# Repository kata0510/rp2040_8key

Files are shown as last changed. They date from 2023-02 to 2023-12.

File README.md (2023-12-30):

# rp2040_8key
[RP2040で作る自作キーボード](https://booth.pm/ja/items/4444554)の第4章で設計したキーボード基板です。

RP2040を用いた8キーの自作キーボード基板です。

検証用のためケースなどは付属しません。RP2040を用いた実際の動作と部品実装例の参考としてご利用ください。

## ファームウェア
ファームウェアは以下のリポジトリの`rp2040_8key`ブランチにあります。Cloneし、ブランチを切り替えてからqmk flashを実行してください。

[https://github.com/kata0510/qmk_firmware/tree/rp2040_8key](https://github.com/kata0510/qmk_firmware/tree/rp2040_8key)

QMK Firmwareのビルド環境未作成の場合は、公式ドキュメントもしくは[RP2040で作る自作キーボード](https://booth.pm/ja/items/4444554)の第2章を参考に構築してください。

[https://docs.qmk.fm/#/newbs_getting_started](https://docs.qmk.fm/#/newbs_getting_started)

```
$ git switch rp2040_8key
$ qmk flash -kb rp2040_8key -km default
```

firmwareフォルダ内にあるファームウェアは書籍の参考用として用意しているものです。お手持ちのqmk_firmwareリポジトリの`keyboards/`以下にフォルダをコピーしても書き込み可能です。

## 基板データについて
基板データは`PCB/`フォルダ以下にあります。Kicad7閲覧することができます。

JLCPCBのPCB Assemblyサービスを想定した部品ファイル(BOM)と配置ファイル(CPL)は`gerver/`フォルダ内にあります。

部品の在庫状況は日々返送するため、在庫無しの場合は同じ性能の部品を選択して製造してください。

## 不具合/問い合わせ
基板の不具合、お問い合わせに関しては以下のメールアドレス、もしくはDiscord(yuchi51)までご連絡ください。
```
yuchi.kbd@gmail.com
```

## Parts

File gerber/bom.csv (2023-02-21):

Comment | Val | Designator | Footprint | JLCPCB Part #
 | 10u | C1-2 | C_0402_1005Metric | C1644
 | 100n | C3-11,C14 | C_0402_1005Metric | C1525
 | 2.2uF | C12-13,C15 | C_0402_1005Metric | C307418
 | D_Small | D1-8 | SOD-123 | C109203
 | 6V 0.5A | F1 | Fuse_0603_1608Metric | C122965
 | USB_C_Receptacle | J1 | USB_C_Receptacle_HRO_TYPE-C-31-M-12 | C165948
 | 1k | R1,R6,R8 | R_0402_1005Metric | C11702
 | 5.1k | R2-3 | R_0402_1005Metric | C25905
 | 27 | R4-5, | R_0402_1005Metric | C25100
 | 10k | R7 | R_0402_1005Metric | C25744
 | 3A/10V/280mV | SD1 | D_SOD-123 | C8598
 | LED_GREEN | STLED1 | LED_0402_1005Metric | C130723
 | SWBoot | SW9-10 | SW_Push_1P1T_NO_Vertical_Wuerth_434133025816 | C92589
 | NCP1117-3.3_SOT223 | U1 | SOT-223 | C146799
 | RP2040 | U2 | QFN-56-1EP_7x7mm_P0.4mm_EP3.2x3.2mm | C2040
 | W25Q128JVPIQ | U3 | WSON-8-1EP_6x5mm_P1.27mm_EP3.4x4.3mm | C97521
 | 12MHz_Q22FA23V00285 | Y1 | Resonator_SMD_Murata_CSTxExxV-3Pin_3.0x1.1mm | C341520

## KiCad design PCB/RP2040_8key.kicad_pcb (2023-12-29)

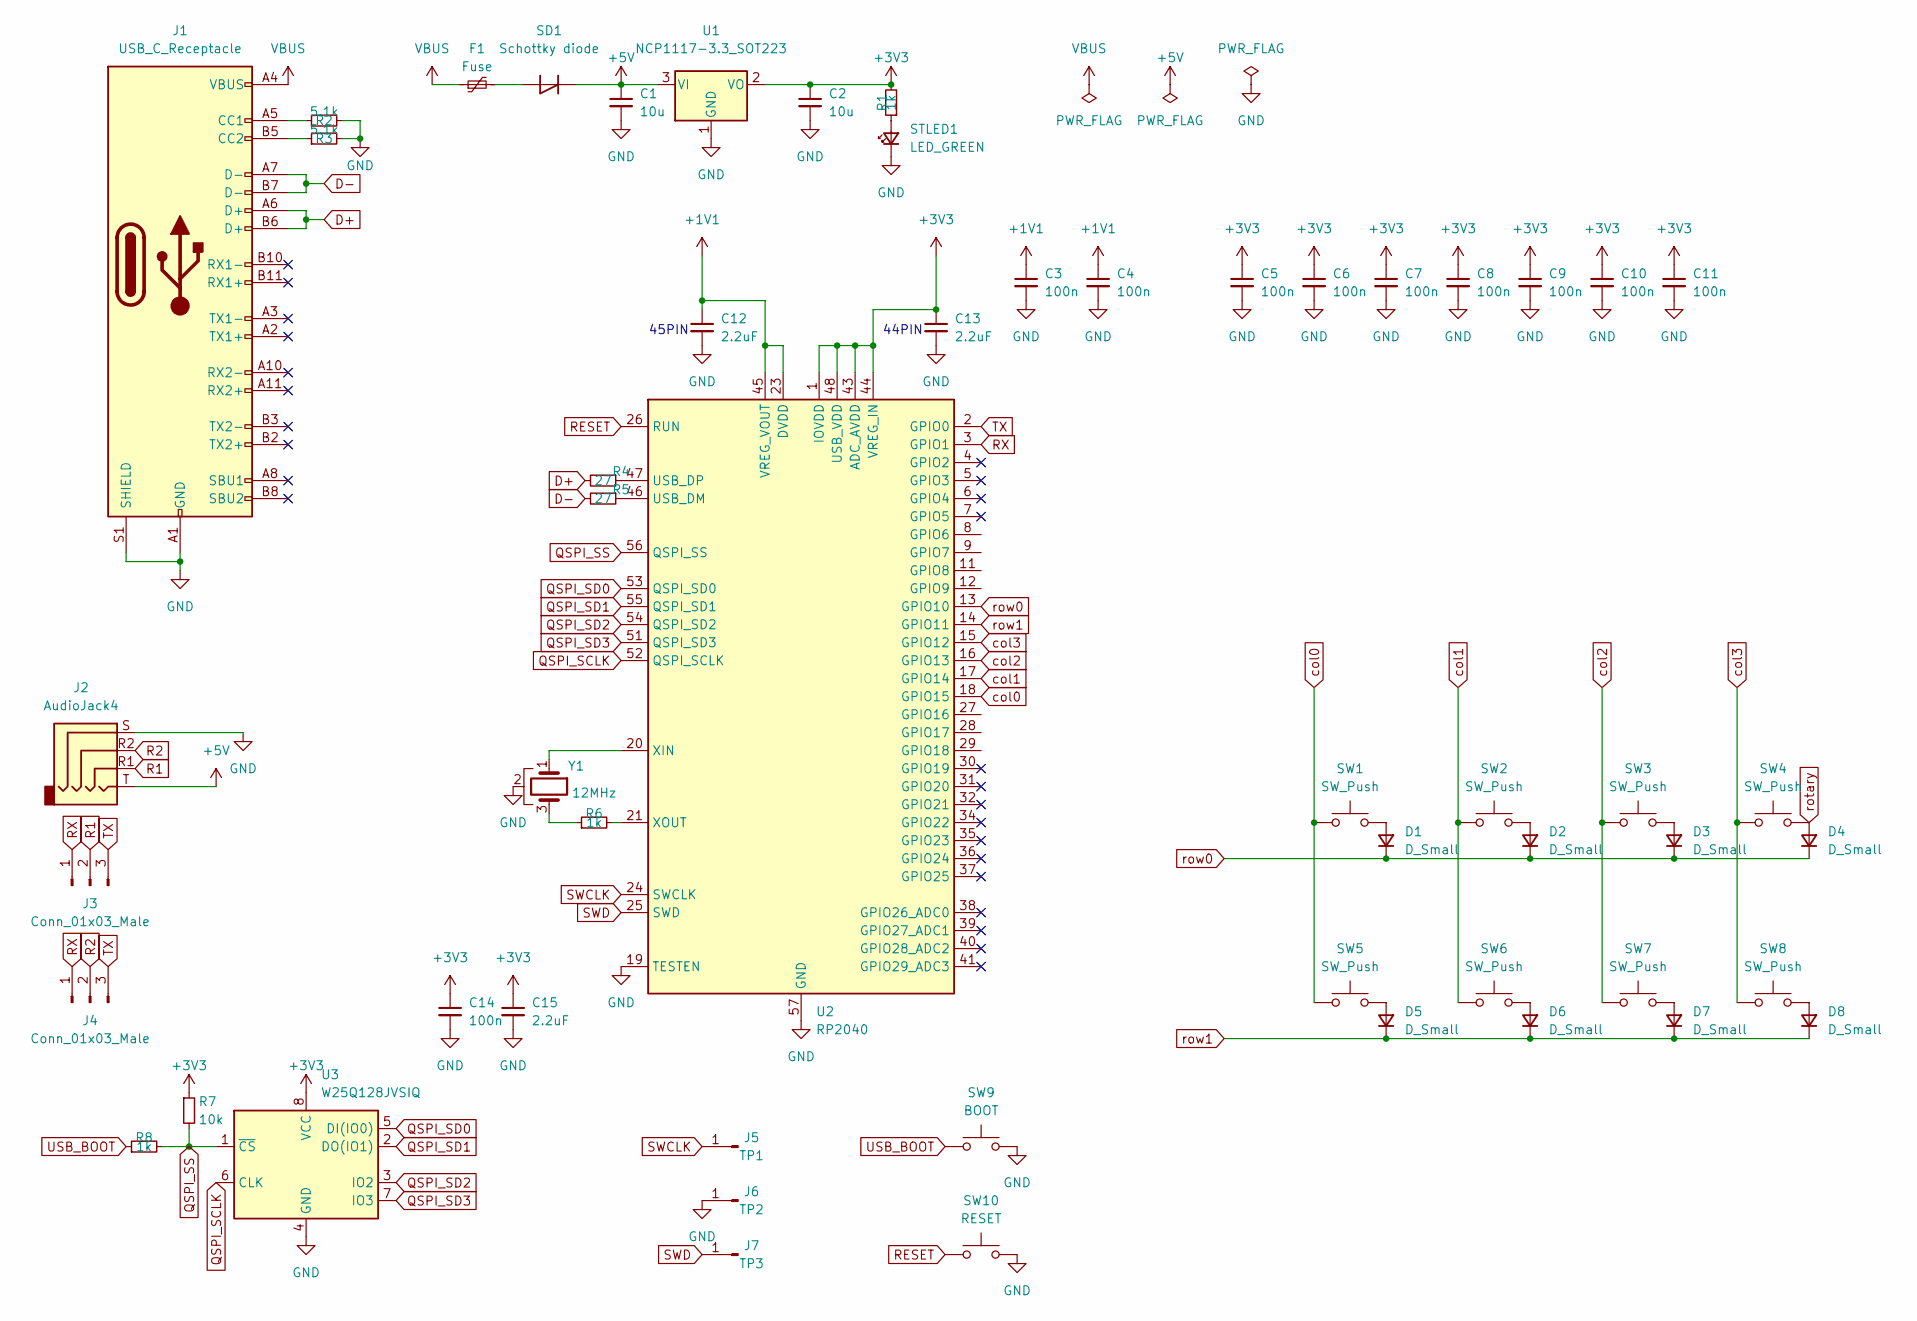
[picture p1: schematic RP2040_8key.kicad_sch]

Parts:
C1, C2: 10u; C_1206_3216Metric
C3, C4, C5, C6, C7, C8, C9, C10, C11, C14: 100n; C_0402_1005Metric
C12, C13, C15: 2.2uF; C_0402_1005Metric
D1, D2, D3, D4, D5, D6, D7, D8: D_Small; D_SOD-123
F1: Fuse; Fuse_0603_1608Metric; LCSC C122965
J1: USB_C_Receptacle; USB_C_Receptacle_HRO_TYPE-C-31-M-12
J2: AudioJack4; PJ-320
J3, J4: Conn_01x03_Male; SolderJumper-3_P1.3mm_Open_Pad1.0x1.5mm_NumberLabels
J5: TP1; TestPoint_Pad_D1.0mm
J6: TP2; TestPoint_Pad_D1.0mm
J7: TP3; TestPoint_Pad_D1.0mm
R1, R6, R8: 1k; R_0402_1005Metric
R2, R3: 5.1k; R_0402_1005Metric
R4, R5: 27; R_0402_1005Metric
R7: 10k; R_0402_1005Metric
SD1: Schottky diode; D_SOD-123
STLED1: LED_GREEN; LED_0402_1005Metric
SW1, SW2, SW3, SW4, SW5, SW6, SW7, SW8: SW_Push; MX_HOLE
SW9: BOOT; SW_SPST_PTS810
SW10: RESET; SW_SPST_PTS810
U1: NCP1117-3.3_SOT223; SOT-223
U2: RP2040; QFN-56-1EP_7x7mm_P0.4mm_EP3.2x3.2mm
U3: W25Q128JVSIQ; WSON-8-1EP_6x5mm_P1.27mm_EP3.4x4.3mm
Y1: 12MHz; Resonator_SMD_Murata_CSTxExxV-3Pin_3.0x1.1mm

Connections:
+1V1: C3.1, C4.1, C12.1, U2.23 (DVDD), U2.45 (VREG_VOUT), U2.50 (DVDD)
+3V3: C2.1, C5.1, C6.1, C7.1, C8.1, C9.1, C10.1, C11.1, C13.1, C14.1, C15.1, R1.2, R7.1, U1.2 (VO), U2.1 (IOVDD), U2.10 (IOVDD), U2.22 (IOVDD), U2.33 (IOVDD), U2.42 (IOVDD), U2.43 (ADC_AVDD), U2.44 (VREG_IN), U2.48 (USB_VDD), U2.49 (IOVDD), U3.8 (VCC)
+5V: C1.1, J2.T, SD1.1 (K), U1.3 (VI)
D+: J1.A6 (D+), J1.B6 (D+), R4.2
D-: J1.A7 (D-), J1.B7 (D-), R5.2
GND: C1.2, C2.2, C3.2, C4.2, C5.2, C6.2, C7.2, C8.2, C9.2, C10.2, C11.2, C12.2, C13.2, C14.2, C15.2, J1.A1 (GND), J1.A12 (GND), J1.B1 (GND), J1.B12 (GND), J1.S1 (SHIELD), J2.S, J6.1, R2.2, R3.2, STLED1.1 (K), SW9.2, SW10.2, U1.1 (GND), U2.19 (TESTEN), U2.57 (GND), U3.4 (GND), Y1.2
unnamed: D1.2 (A), SW1.2
unnamed: D2.2 (A), SW2.2
unnamed: D3.2 (A), SW3.2
unnamed: D5.2 (A), SW5.2
unnamed: D6.2 (A), SW6.2
unnamed: D7.2 (A), SW7.2
unnamed: D8.2 (A), SW8.2
unnamed: J1.A5 (CC1), R2.1
unnamed: J1.B5 (CC2), R3.1
unnamed: R6.1, Y1.3
unnamed: F1.2, SD1.2 (A)
unnamed: R1.1, STLED1.2 (A)
unnamed: R5.1, U2.46 (USB_DM)
unnamed: R4.1, U2.47 (USB_DP)
unnamed: U2.20 (XIN), Y1.1
unnamed: R6.2, U2.21 (XOUT)
QSPI_SCLK: U2.52 (QSPI_SCLK), U3.6 (CLK)
QSPI_SD0: U2.53 (QSPI_SD0), U3.5 (DI(IO0))
QSPI_SD1: U2.55 (QSPI_SD1), U3.2 (DO(IO1))
QSPI_SD2: U2.54 (QSPI_SD2), U3.3 (IO2)
QSPI_SD3: U2.51 (QSPI_SD3), U3.7 (IO3)
QSPI_SS: R7.2, R8.2, U2.56 (QSPI_SS), U3.1 (~CS)
R1: J2.R1, J3.2
R2: J2.R2, J4.2
RESET: SW10.1, U2.26 (RUN)
RX: J3.1, J4.1, U2.3 (GPIO1)
SWCLK: J5.1, U2.24 (SWCLK)
SWD: J7.1, U2.25 (SWD)
TX: J3.3, J4.3, U2.2 (GPIO0)
USB_BOOT: R8.1, SW9.1
VBUS: F1.1, J1.A4 (VBUS), J1.A9 (VBUS), J1.B4 (VBUS), J1.B9 (VBUS)
col0: SW1.1, SW5.1, U2.18 (GPIO15)
col1: SW2.1, SW6.1, U2.17 (GPIO14)
col2: SW3.1, SW7.1, U2.16 (GPIO13)
col3: SW4.1, SW8.1, U2.15 (GPIO12)
rotary: D4.2 (A), SW4.2
row0: D1.1 (K), D2.1 (K), D3.1 (K), D4.1 (K), U2.13 (GPIO10)
row1: D5.1 (K), D6.1 (K), D7.1 (K), D8.1 (K), U2.14 (GPIO11)

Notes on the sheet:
45PIN
44PIN

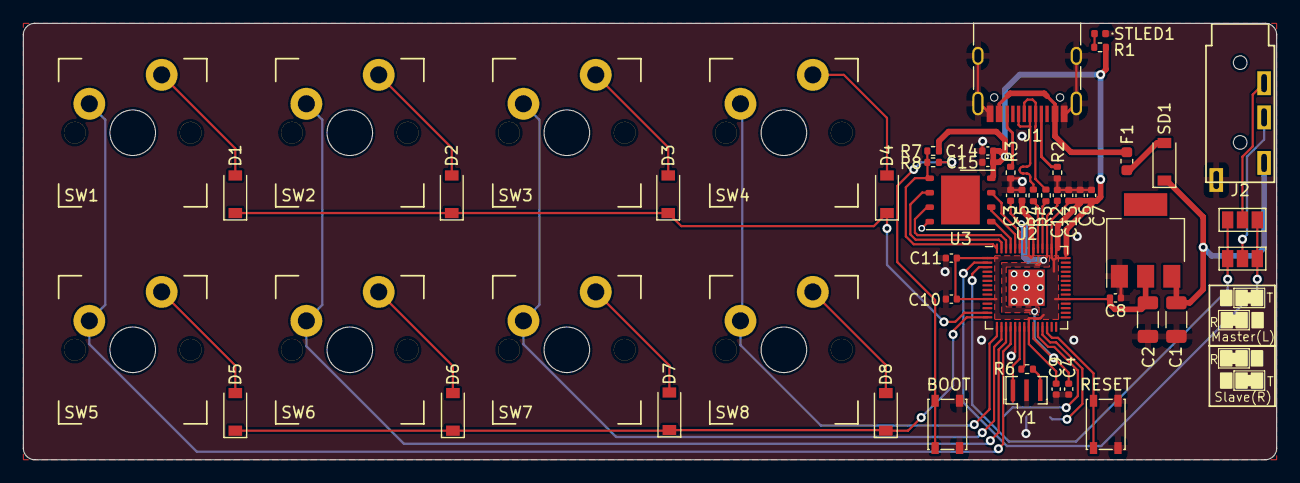
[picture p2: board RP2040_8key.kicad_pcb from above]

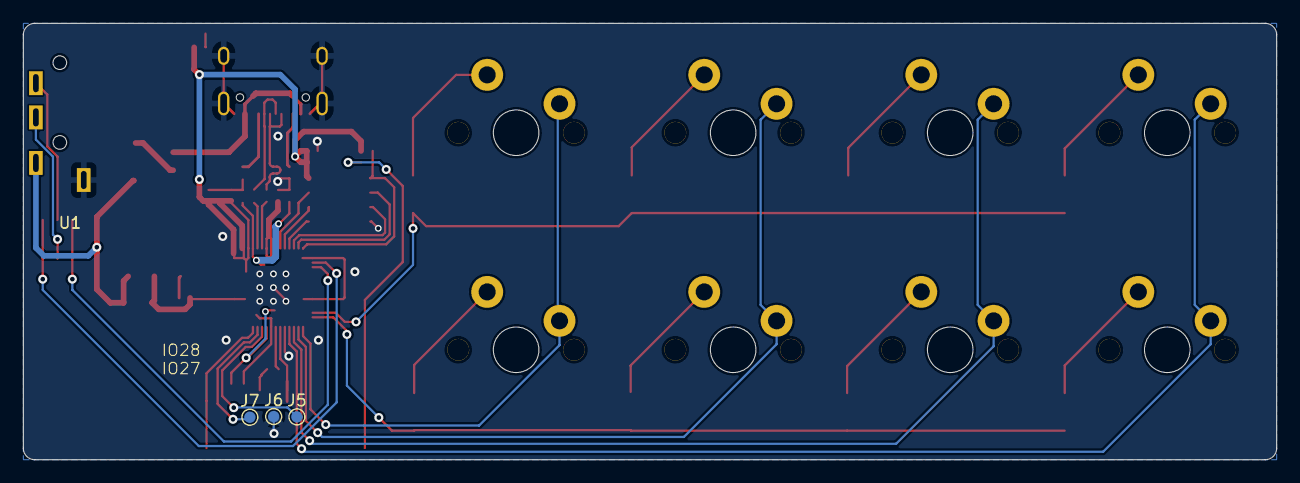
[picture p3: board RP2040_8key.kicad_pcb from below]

Board: 2 copper layers, 110.0 x 38.3 mm, 55 parts (3 on the bottom side), 44 nets.

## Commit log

2022-12-26 Add kicad files
    [RP2040_8key.kicad_pcb, RP2040_8key.kicad_sch]
2022-12-30 Add firmware gerber
    [RP2040_8key-B_Cu.gbr, RP2040_8key-B_Mask.gbr, RP2040_8key-B_Paste.gbr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]
2023-02-21 fix bom
    [bom.csv]
2023-12-29 Update 2023Version
    [RP2040_8key-B_Cu.gbr, RP2040_8key-B_Mask.gbr, RP2040_8key-B_Paste.gbr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]
2023-12-30 breadboardのファームウェアは削除
2023-12-30 基板データを移動
    [RP2040_8key.kicad_pcb, RP2040_8key.kicad_sch]
